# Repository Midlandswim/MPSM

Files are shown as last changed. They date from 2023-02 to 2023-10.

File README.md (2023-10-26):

# MPSM Research
Modular Power Source Management 

Researcher: Wilson Dhalwani <br />
Advisor: Mr. Michael Liva (BCA) <br />
Context: General Research with Specialization in Electrical Engineering <br />
Projekt Name: Modular Power Source Management System <br />
Start Date: September 30, 2022 <br />

The following repository is for documenting and sharing my work in this research project and its related fields of engineering. This was also made for recording my process of solving the issue at hand so that others can learn and build upon my work. The MPSM system was created to help address the issue of one of the basics of engineering research and design: power. Almost all of the research projects coming out of our engineering labs at BCA require some degree of power source management, namely with rechargeable lipo batteries, and with the new way of clean, renewable energy, it is a coming must. The MPSM was made to solve that issue, with its modular aspect and customizable ability allowing for quick and effective implementation into most projects. The hope and goal is that others can implement this into their projects, saving time and effort, as well as having the confidence in a powerful system to boot up some of their greatest creations. The greatest innovations are not the ones that allow a man to jump but to confidently step up. This project has no end date as innovation never ends, rather, continues until the idea is forgotten, and my hope is that this work can be the basis for future engineers who, too, find great excitement in innovation and design. <br />

Should you have any questions, comments, or just wish to reach out, email me at wilson.dhalwani@gmail.com !

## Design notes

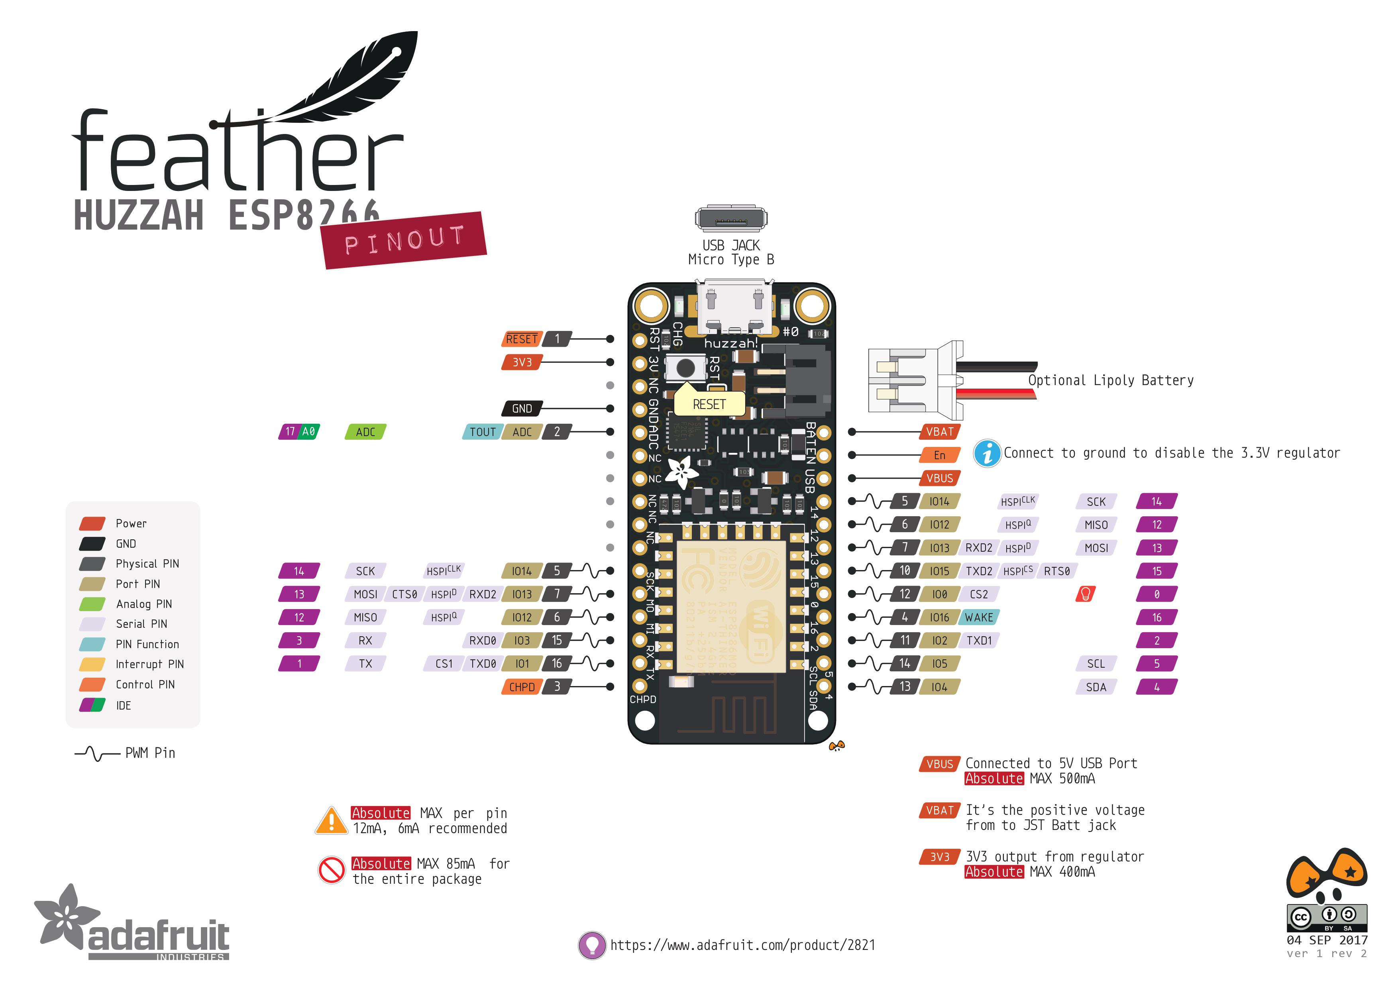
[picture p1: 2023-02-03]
Documents/Miscellaneous/Huzzah_ESP8266_Pinout_v1.2.jpg

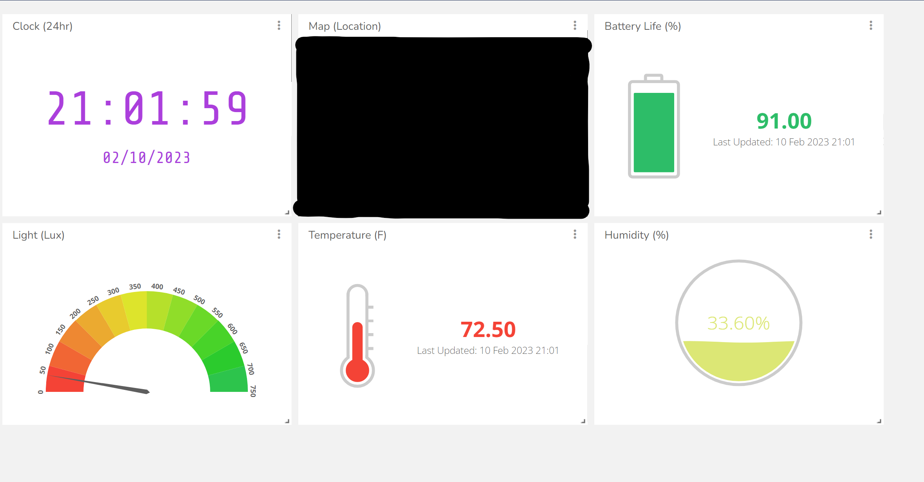
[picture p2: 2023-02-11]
Media/Ubidots/UbidotsDashboard.png

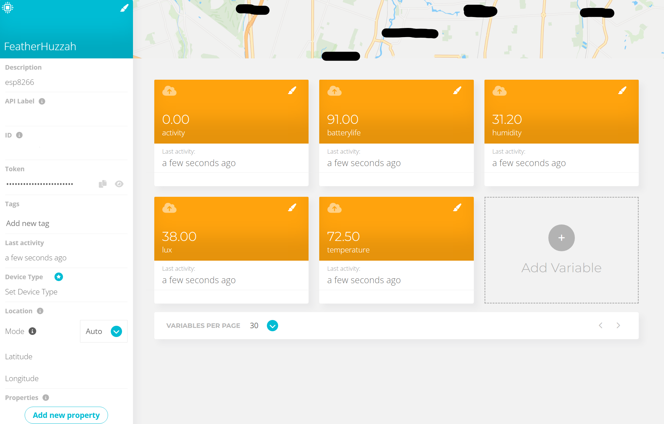
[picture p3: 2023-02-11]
Media/Ubidots/UbidotsDevice.png

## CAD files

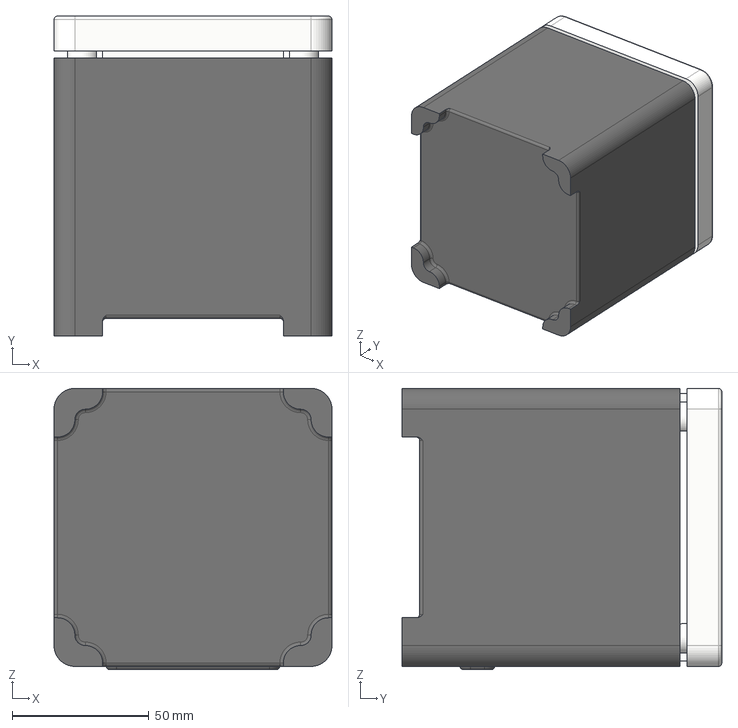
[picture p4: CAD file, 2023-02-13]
CAD/Version 2.0/MPSMEnclosure v2.step
101.6 x 116.8 x 102.8 mm

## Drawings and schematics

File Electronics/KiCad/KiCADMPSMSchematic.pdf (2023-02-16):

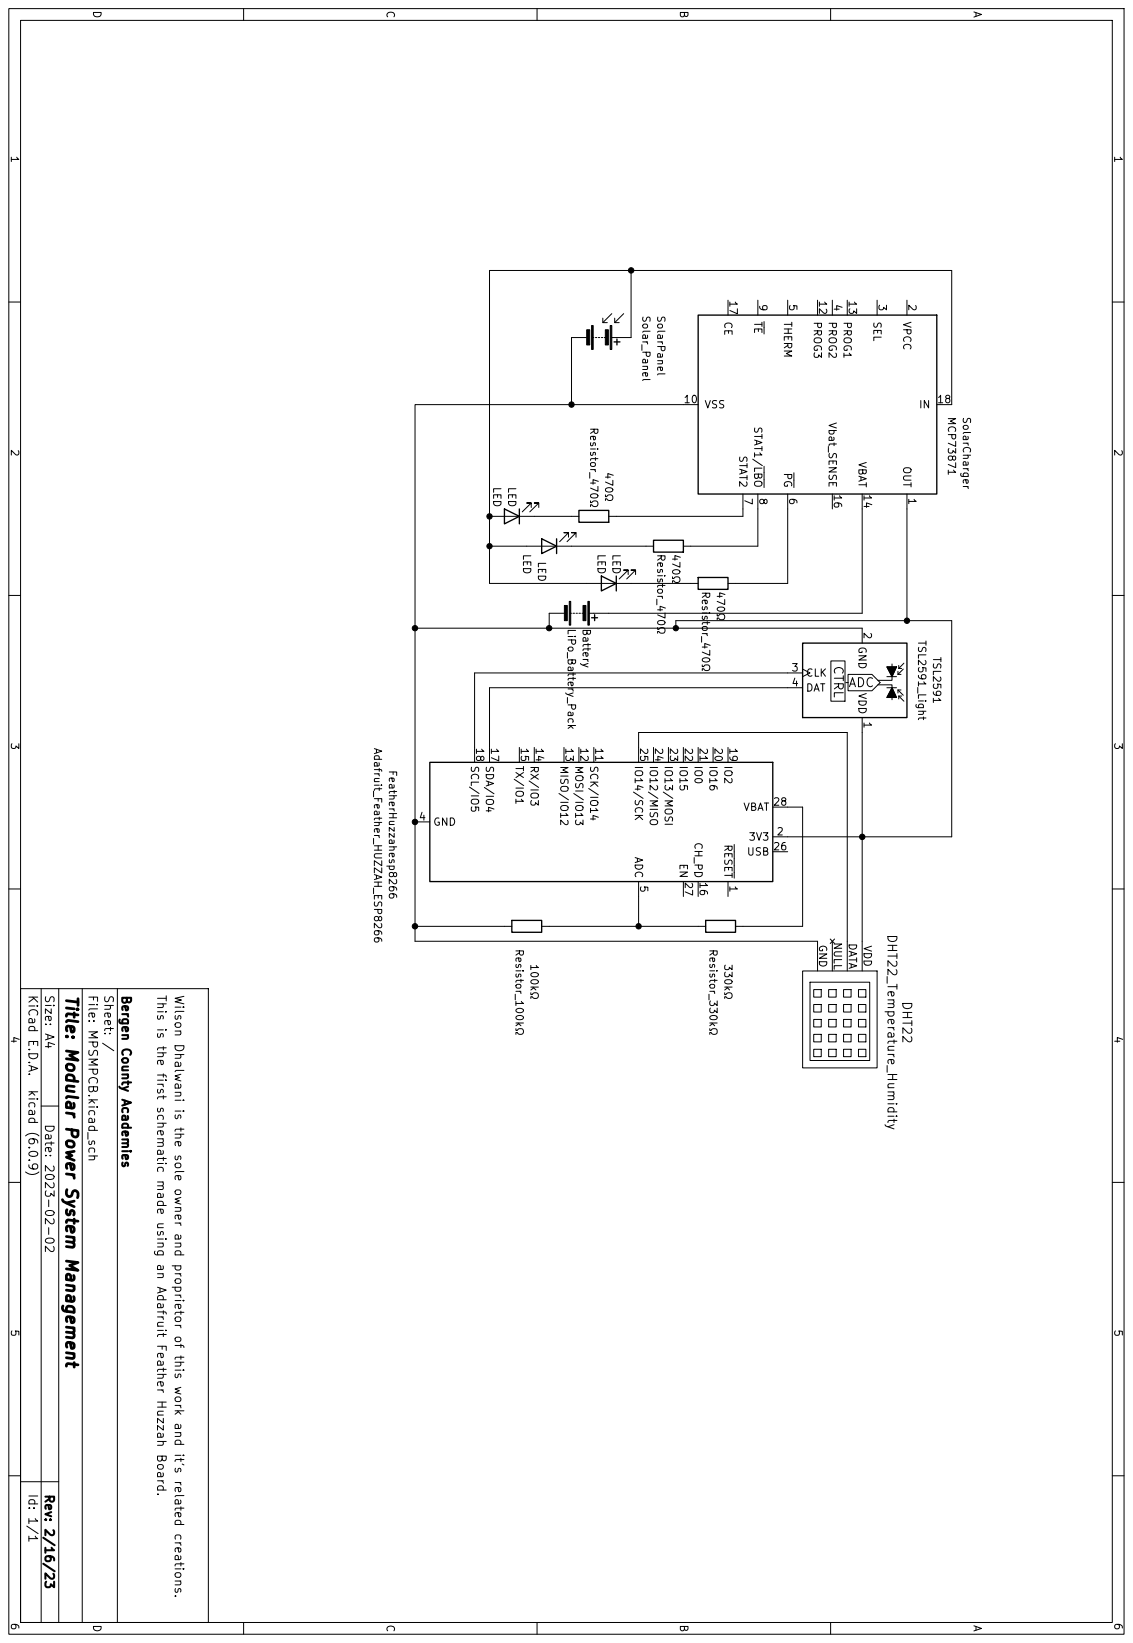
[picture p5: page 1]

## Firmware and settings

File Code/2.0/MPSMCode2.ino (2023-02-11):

/*
  Projekt: MPSM
  Names: Wilson Dhalwani 
  Advisor: Mr. Liva (BCA)
  Class: Engineering Research
  Date: 01/30/2023 
  Last Updated: 02/10/2023
  Notes: 
    -Made using the Arduino IDE for the Adafruit Feather Huzzah esp8266 
    -Some code was taken from the TSL2591 Library from Adafruit, that code does not belong to me, the rest was written by yours truly!
    -Ignore all my comments, some of this code was written at the dead of night, and so my contextual sanity was questionable... (haha)
    -Replace the Wifi Credentials with your own network (or the one you're currently veiwing this on)
*/

//Libraries
#include <DHT.h>
#include <LiquidCrystal.h>
#include <Wire.h>
#include <math.h>
#include <Adafruit_Sensor.h>
#include "Adafruit_TSL2591.h"
#include "Ubidots.h"
#include <Ubidots.h>

//Constants, announcements, and the other fun stuff that belongs here; we live in a society
//DHT22
#define DHTPIN 14          //digiPin
#define DHTTYPE DHT22      // DHT 22  (AM2302)
DHT dht(DHTPIN, DHTTYPE);  //Initialize DHT sensor for normal 16mhz Arduino
float hum;                 //Stores humidity value
float temp;                //Stores temperature value
int tempF;                 //tempvalue in Farenheit
//TSL2591
Adafruit_TSL2591 tsl = Adafruit_TSL2591(2591);
int lux;  //lux
//battLife
int prcnt;  //batterylife percent
int raw;    //raw read value from A0 or 17
int volt;   //inital volt conversion with decent degree of errorkvk
int volt2;  //secondary volt conversion with minimal degree of error
//wifi
const char* UBIDOTS_TOKEN = "BBFF-kdcXABSmCfmapAA4LTDLU59WMhIBY7";      //UbidotsToken
const char* WIFI_SSID = "WIFISSIDHere";                                 //WifiSSID
const char* WIFI_PASS = "WIFIPASSHere";                                 //WifiPass
Ubidots ubidots(UBIDOTS_TOKEN, UBI_HTTP);

//Config Functions
void displaySensorDetails(void) {
  sensor_t sensor;
  tsl.getSensor(&sensor);
  Serial.println(F("------------------------------------"));
  Serial.print(F("Sensor:       "));
  Serial.println(sensor.name);
  Serial.print(F("Driver Ver:   "));
  Serial.println(sensor.version);
  Serial.print(F("Unique ID:    "));
  Serial.println(sensor.sensor_id);
  Serial.print(F("Max Value:    "));
  Serial.print(sensor.max_value);
  Serial.println(F(" lux"));
  Serial.print(F("Min Value:    "));
  Serial.print(sensor.min_value);
  Serial.println(F(" lux"));
  Serial.print(F("Resolution:   "));
  Serial.print(sensor.resolution, 4);
  Serial.println(F(" lux"));
  Serial.println(F("------------------------------------"));
  Serial.println(F(""));
  delay(500);
}
void configureSensor(void) {
  // You can change the gain on the fly, to adapt to brighter/dimmer light situations
  //tsl.setGain(TSL2591_GAIN_LOW);    // 1x gain (bright light)
  tsl.setGain(TSL2591_GAIN_MED);  // 25x gain
  //tsl.setGain(TSL2591_GAIN_HIGH);   // 428x gain

  // Changing the integration time gives you a longer time over which to sense light
  // longer timelines are slower, but are good in very low light situtations!
  //tsl.setTiming(TSL2591_INTEGRATIONTIME_100MS);  // shortest integration time (bright light)
  // tsl.setTiming(TSL2591_INTEGRATIONTIME_200MS);
  tsl.setTiming(TSL2591_INTEGRATIONTIME_300MS);
  // tsl.setTiming(TSL2591_INTEGRATIONTIME_400MS);
  // tsl.setTiming(TSL2591_INTEGRATIONTIME_500MS);
  // tsl.setTiming(TSL2591_INTEGRATIONTIME_600MS);  // longest integration time (dim light)Serial.println(F("------------------------------------"));
  Serial.print(F("Gain:         "));
  tsl2591Gain_t gain = tsl.getGain();
  switch (gain) {
    case TSL2591_GAIN_LOW:
      Serial.println(F("1x (Low)"));
      break;
    case TSL2591_GAIN_MED:
      Serial.println(F("25x (Medium)"));
      break;
    case TSL2591_GAIN_HIGH:
      Serial.println(F("428x (High)"));
      break;
    case TSL2591_GAIN_MAX:
      Serial.println(F("9876x (Max)"));
      break;
  }
  Serial.print(F("Timing:       "));
  Serial.print((tsl.getTiming() + 1) * 100, DEC);
  Serial.println(F(" ms"));
  Serial.println(F("------------------------------------"));
  Serial.println(F(""));
}
void TSLconfig(void) {
  Serial.println(F("Starting Adafruit TSL2591 Test!"));

  if (tsl.begin()) {
    Serial.println(F("Found a TSL2591 sensor"));
  } else {

    Serial.println(F("No sensor found ... check your wiring?"));
    while (1)
      ;
  }
  /* Display some basic information on this sensor */
  displaySensorDetails();
  /* Configure the sensor */
  configureSensor();
}
void initializerConfig(void) {
  //initilize sensors
  dht.begin();
  TSLconfig();
  //wifi initialize
  ubidots.wifiConnect(WIFI_SSID, WIFI_PASS);
  //ubidots.setDebug(true);                        //Uncomment for printing debug msgs
}

//Processing Functions
//TSL2591 Calculation Functions
//Shows how to perform a basic read on visible, full spectrum or infrared light (returns raw 16-bit ADC values)
void simpleRead(void) {
  // Simple data read example. Just read the infrared, fullspecrtrum diode
  // or 'visible' (difference between the two) channels.
  // This can take 100-600 milliseconds! Uncomment whichever of the following you want to read
  uint16_t x = tsl.getLuminosity(TSL2591_VISIBLE);
  //uint16_t x = tsl.getLuminosity(TSL2591_FULLSPECTRUM);
  //uint16_t x = tsl.getLuminosity(TSL2591_INFRARED);

  Serial.print(F("[ "));
  Serial.print(millis());
  Serial.print(F(" ms ] "));
  Serial.print(F("Luminosity: "));
  Serial.println(x, DEC);
}
//Show how to read IR and Full Spectrum at once and convert to lux
void advancedRead(void) {
  // More advanced data read example. Read 32 bits with top 16 bits IR, bottom 16 bits full spectrum
  // That way you can do whatever math and comparisons you want!
  uint32_t lum = tsl.getFullLuminosity();
  uint16_t ir, full;
  ir = lum >> 16;
  full = lum & 0xFFFF;
  // Serial.print(F("[ "));
  // Serial.print(millis());
  // Serial.print(F(" ms ] "));
  // Serial.print(F("IR: "));
  // Serial.print(ir);
  // Serial.print(F("  "));
  // Serial.print(F("Full: "));
  // Serial.print(full);
  // Serial.print(F("  "));
  // Serial.print(F("Visible: "));
  // Serial.print(full - ir);
  // Serial.print(F("  "));
  // Serial.print(F("Lux: "));
  // Serial.println(tsl.calculateLux(full, ir), 6);
  lux = tsl.calculateLux(full, ir);
}
//Performs a read using the Adafruit Unified Sensor API.
void unifiedSensorAPIRead(void) {
  /* Get a new sensor event */
  sensors_event_t event;
  tsl.getEvent(&event);
  /* Display the results (light is measured in lux) */
  Serial.print(F("[ "));
  Serial.print(event.timestamp);
  Serial.print(F(" ms ] "));
  if ((event.light == 0) | (event.light > 4294966000.0) | (event.light < -4294966000.0)) {

    /* If event.light = 0 lux the sensor is probably saturated */
    /* and no reliable data could be generated! */
    /* if event.light is +/- 4294967040 there was a float over/underflow */
    Serial.println(F("Invalid data (adjust gain or timing)"));
  } else {
    Serial.print(event.light);
    Serial.println(F(" lux"));
  }
}
void lightRead(void) {
  //simpleRead();
  advancedRead();
  //unifiedSensorAPIRead();
  Serial.print("Lux: ");
  Serial.println(lux);
}
//DHT22 Calculation Functions
void humidTempRead(void) {
  hum = dht.readHumidity();
  temp = dht.readTemperature();
  int tempF = (temp * 9 / 5) + 32;
  //Print temp and humidity values to serial monitor
  Serial.print("Humidity: ");
  Serial.print(hum);
  Serial.print(" %");
  //Serial.print(" %, Temp: ");
  //Serial.print(temp);
  //Serial.print(" Celsius");
  Serial.print(", Temperature: ");
  Serial.print(tempF);
  Serial.println(" F");
}
//BatteryLife Calculation Functions
void battRead(void) {
  //add calculations for battery life
  int raw = analogRead(A0);
  //Serial.println(raw);
  float volt = 0.0042 * raw - 0.0022;  //found using excell graphing; trendline
  //Serial.println(volt);
  float volt2 = 1.0007 * volt - 0.0802;  //improves calculation accuracy; used excel graphing; trendline
  //Serial.println(volt2);
  int prcnt = map(raw, 0, 1024, 0, 100);
  int battery = prcnt;
  if (volt2 < 3.0 || volt2 > 4.2) {  //debug check for volatge check
    Serial.println("DANGER! INSUFFICENT VOLTAGE!");
  } else {
    Serial.print("Battery Life: ");
    Serial.print(prcnt);
    Serial.println("%");
  }
}
//Wifi&Server Send Functions
void packetSend(void) {

  //battery nonsense
  int raw = analogRead(A0);
  //Serial.println(raw);
  float volt = 0.0042 * raw - 0.0022;  //found using excell graphing; trendline
  //Serial.println(volt);
  float volt2 = 1.0007 * volt - 0.0802;  //improves calculation accuracy; used excel graphing; trendline
  //Serial.println(volt2);
  int prcnt = map(raw, 0, 1024, 0, 100);
  int battery = prcnt;

  ubidots.add("Temperature", (temp * 9 / 5) + 32);  //converts from C to F (for some reason it doesn't work if I convert it above)
  ubidots.add("Humidity", hum);
  ubidots.add("BatteryLife", battery);
  ubidots.add("Lux", lux);

  bool bufferSent = false;
  bufferSent = ubidots.send();  // Will send data to a device label that matches the device Id

  if (bufferSent) {
    // Do something if values were sent properly
    Serial.println("Packets Sent!");
  }
}

//Board Startup Function
void setup() {
  //initialize board
  Serial.begin(115200);  //baud rate
  //initliize eveyrthing else
  initializerConfig();
}

//Board Activity Function
void loop() {
  //Read and Print Temp/Humidiity Info
  humidTempRead();

  //Read and Print Light Info
  lightRead();

  //Read and Print BatteryLife Info
  battRead();

  //UbiDots Send Schpiel
  packetSend();

  //generalDelay
  delay(60000);  //dely 2.5 sec
}

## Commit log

2023-02-03 Voltage Graphing and Conversion Sheet
    This Microsoft Excel sheet was used to find, graph, and convert the different voltages related to my project. These specifically dealt with the lipo battery and reading its battery life.
    [Wilson_Voltage_ADC_to_Actual_Value_Converison.xlsx]
2023-02-03 Images for the First Version
    This was a simple design using an Arduino Uno R3. We had most of the data displayed from the Serial Monitor from the Arduino IDE, but some things, such as temperature, showed up on an LCD panel. The main issue was that the Arduino board was not wifi capable, and there was a need for an onboard JST capable plug.
2023-02-11 Version3 Images
    Version 2 but more compact and clean, wire coded too :)
2023-02-11 Reuploaded xlsx file
    There was an error with last title, this one is exact same with appropriate file name
    [Voltage_ADC_to_Actual_Value_Converison Big Battery.xlsx]
2023-02-11 Delete Huzzah_ESP8266_Pinout_v1.2.xlsx
    wrong title
    [Huzzah_ESP8266_Pinout_v1.2.xlsx]
2023-02-11 Ubidots Media
    Added screenshots of the live dashboard and the live device pages.
    Info from the device page has been blurred out or removed for privacy and security concerns.
2023-02-13 Basic Enclosure
    This is a very basic enclosure I made for the MPSM. It will house the basic circuitry, the solar panel in the lid, and the battery. This was made using Autodesk Fusion 360 and exported as a STEP file.
    [MPSMEnclosure v2.step]
2023-02-16 Solar Charger Datasheet
    Datasheet for the solar charger
2023-02-16 MPSM Schematic
    Electronics Schematic for the MPSM. Made using KiCAD
